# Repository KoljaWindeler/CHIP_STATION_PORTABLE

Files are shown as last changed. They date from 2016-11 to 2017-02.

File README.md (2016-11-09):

# CHIP_STATION_PORTABLE
This project is about a better and gaming compatible housing for C.H.I.P.

PocketChip is a great toy to play with, but the keys tend to be hard to push and make some hard click noises. 
The PSP seems like the perfect housing for a CHIP.

Just to mention some features:
 - it has a parallel display that was almost compatible with chip (only requires small amount of hardware)
 - many buttons (4 for the directions + 4 [x,y,a,b] + 2 shoulder buttons + menu buttons (vol+, vol-, ...) ..)
 - status LEDs for power / charging controllable on the LOW end (+5V is directly connected to the LED) 
 - 3.7V lipo battery which should work directly with chips battery circuit
 - 5V input for charging, perfect for chip
 
The purpose of this project is to create a mainboard that acts as an adapter between C.H.I.P. and the PSP.
It shall have the same form factor as the original PSP mainboard and connect easy to the existing flex connectors,
e.g. the buttons and the display. It shall also carry the DC/DC converter circuit to power the display backlight
and accomplish the conversion of the display signals. It shall also provide the required software and firmware files
for chip to use the PSP hardware.

All this will be documeted at https://bbs.nextthing.co/t/csp-chipstationportable/11171
JKW

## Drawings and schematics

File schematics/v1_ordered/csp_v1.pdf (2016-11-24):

A

A

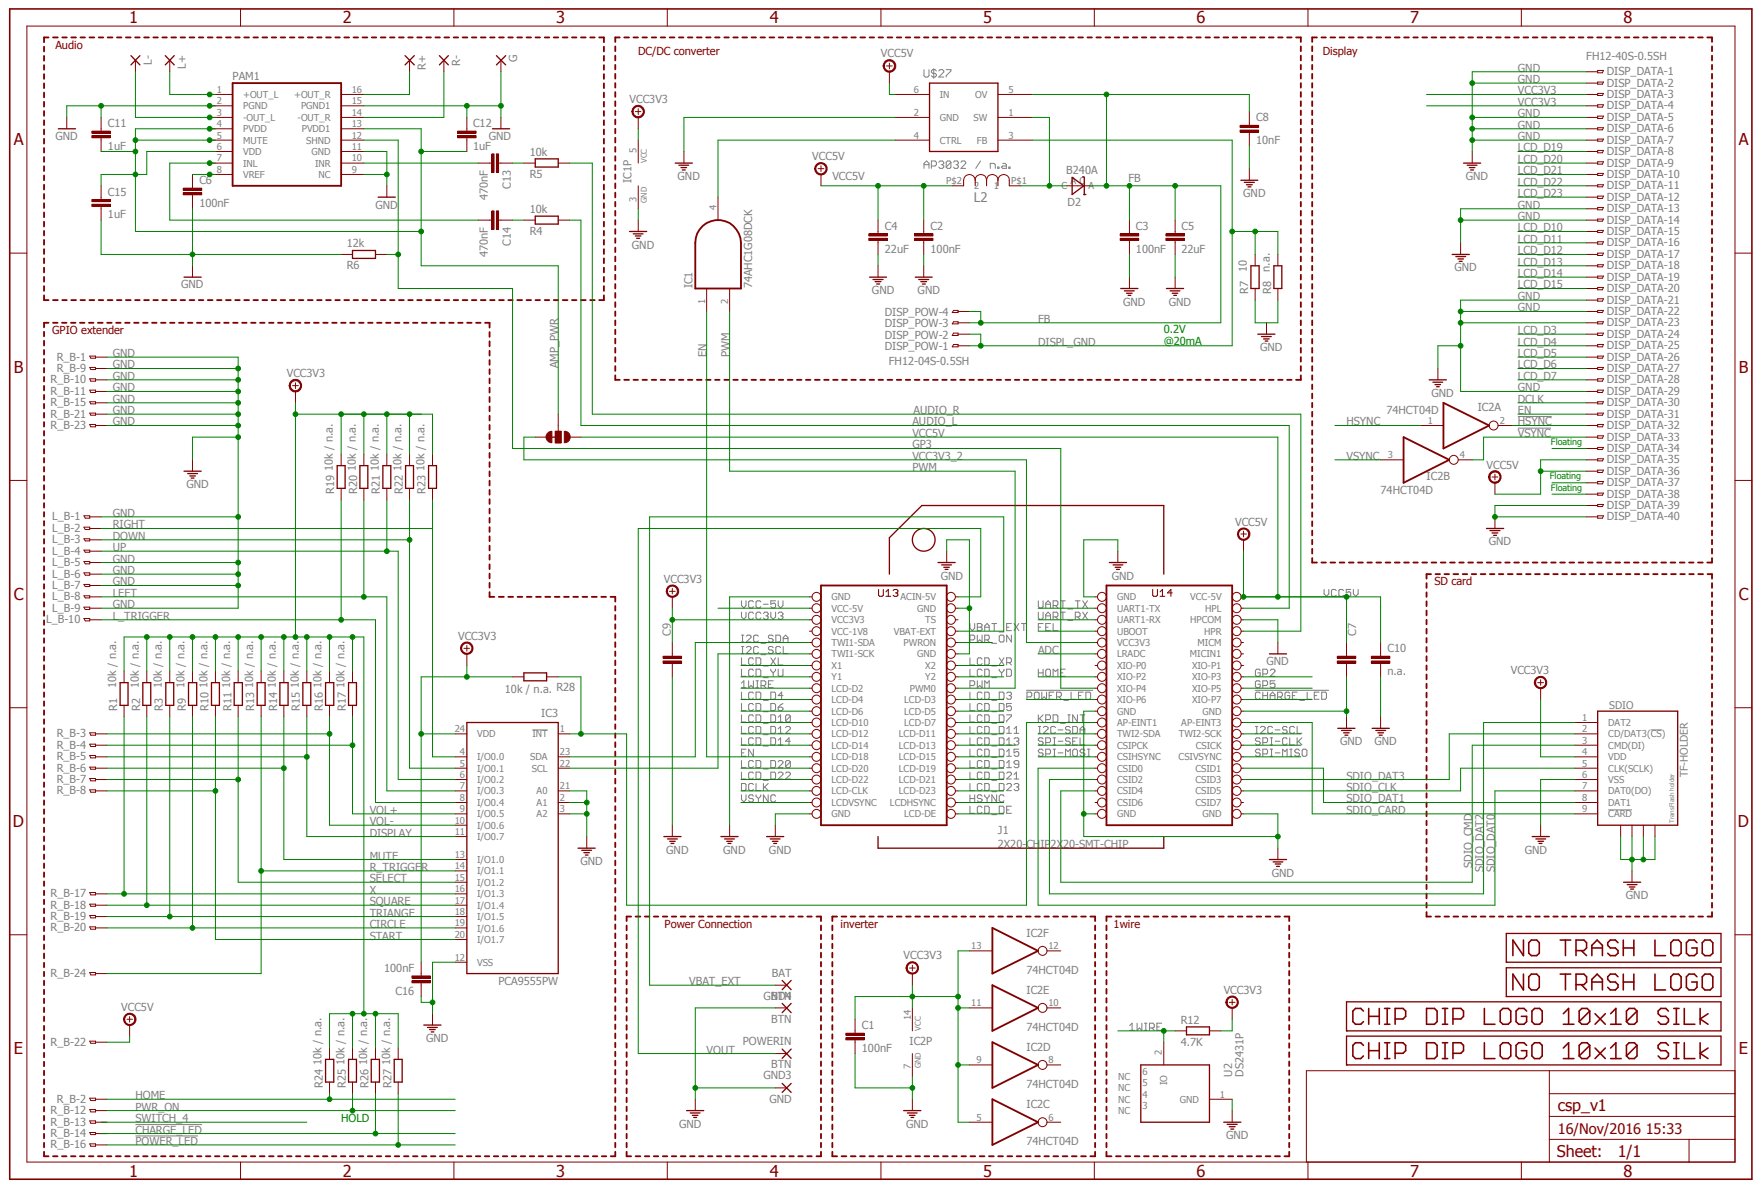
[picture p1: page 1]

VCC3V3_2
PWM

VOL-
DISPLAY
MUTE
SELECT
SQUARE
TRIANGE
CIRCLE
START

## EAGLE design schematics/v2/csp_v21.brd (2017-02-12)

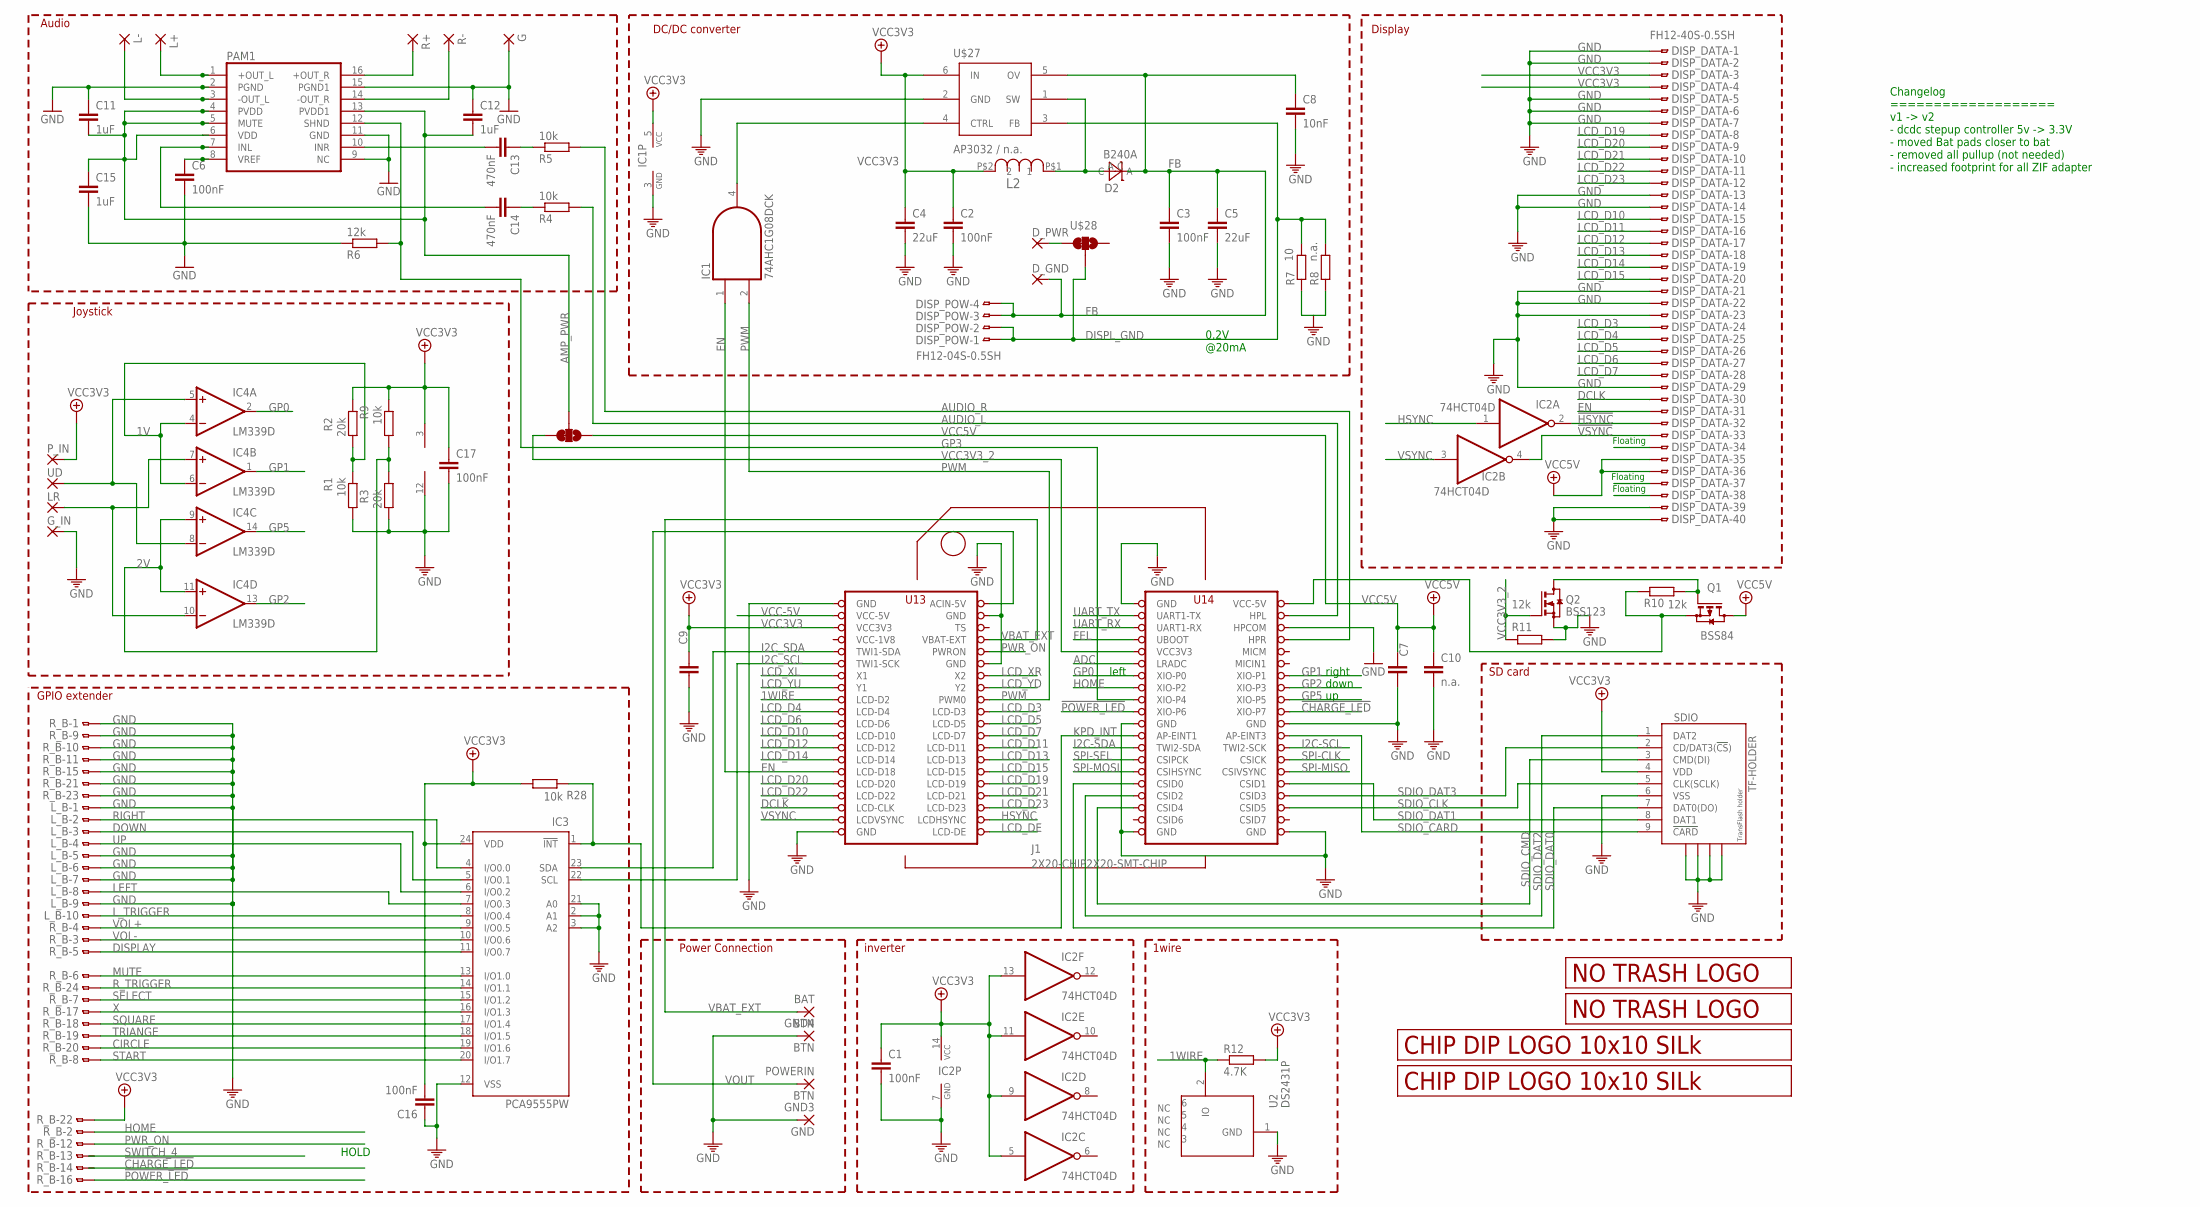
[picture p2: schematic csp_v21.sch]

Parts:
BAT: BTN; SMD1,27-2,54
C1, C2, C3, C6, C16, C17: 100nF; C0805
C4, C5: 22uF; C1206
C7, C9, C10: n.a.; C0805
C8: 10nF; C0805
C11, C12, C15: 1uF; C0805
C13, C14: 470nF; C0805
D2: B240A; DO-214AC
DISP_DATA: FH12-40S-0.5SH
DISP_POW: FH12-04S-0.5SH
D_GND: D_GND; SMD1,36-3
D_PWR: D_PWR; SMD1,36-3
G: 1,6/0,8
GND3: GND; SMD1,27-2,54
GND4: BTN; SMD1,27-2,54
G_IN: BTN; SMD1,36-3
IC1: 74AHC1G08DCK; SC70-5
IC2: 74HCT04D; SO14
IC3: PCA9555PW; TSSOP24
IC4: LM339D; SO14
J1: 2X20-CHIP2X20-SMT-CHIP; 2XAWHW40_G_SMD_R
L2: SRN6045-100M; SRN6045
L+: 1,6/0,8
L-: 1,6/0,8
LR: BTN; SMD1,36-3
L_B: FH12-10S-0.5SH
PAM1: PAM8403; SOP-16
POWERIN: BTN; SMD1,27-2,54
P_IN: BTN; SMD1,36-3
Q1: BSS84; SOT23
Q2: BSS123; SOT23
R1, R9, R28: 10k; M0805
R2, R3: 20k; M0805
R4, R5: 10k; R0805
R6, R10, R11: 12k; R0805
R7: 10; M0805
R8: n.a.; M0805
R12: 4.7K; M0805
R+: 1,6/0,8
R-: 1,6/0,8
R_B: FH12-24S-0.5SH
SDIO: TF-HOLDER; TF-PULL
SJ3: SMD_SJ_3WAY_CLOSED
U2: DS2431P; TSOC6
U$2, U$5: LOGO_10X10_SILK; LOGO2_10X10_SILK
U$3: LOGO_NO_TRASHROHS; LOGO_ROHS_SYM
U$4: LOGO_NO_TRASHNO_TRASH; LOGO_ROHS_NO_TRASH
U$27: AP3032 / n.a.; SOT23-6
U$28: SMD_SJ_3WAY_CLOSED
UD: BTN; SMD1,36-3

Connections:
1V: IC4.4 (-IN), IC4.6 (-IN), R1.1, R2.2
1WIRE: J1.LCD-D2, R12.1, U2.2 (IO)
2V: IC4.9 (+IN), IC4.11 (+IN), R3.1, R9.2
!CHARGE_LED: J1.XIO-P7, R_B.14
!HSYNC: DISP_DATA.32, IC2.2 (O)
!POWER_LED: J1.XIO-P6, R_B.16
!VSYNC: DISP_DATA.33, IC2.4 (O)
ADC: J1.LRADC
AMP_PWR: C11.2, C12.2, C15.1, PAM1.4 (PVDD), PAM1.5 (MUTE), PAM1.6 (VDD), PAM1.13 (PVDD1), SJ3.2
AUDIO_L: J1.HPL, R4.2
AUDIO_R: J1.HPR, R5.2
CIRCLE: IC3.19 (I/O1.6), R_B.20
DCLK: DISP_DATA.30, J1.LCD-CLK
DISPLAY: IC3.11 (I/O0.7), R_B.5
DISPL_GND: DISP_POW.1, DISP_POW.2, R7.2, R8.2, U$27.3 (FB), U$28.2
DOWN: IC3.5 (I/O0.1), L_B.3
EN: DISP_DATA.31, IC1.1 (I0), J1.LCD-D18
FB: C3.1, C5.1, C8.1, D2.C, DISP_POW.3, DISP_POW.4, D_GND.P$1, U$27.5 (OV)
FEL: J1.FEL (UBOOT)
GND: C1.2, C2.2, C3.2, C4.2, C5.2, C6.2, C7.2, C8.2, C9.2, C10.2, C11.1, C12.1, C15.2, C16.1, C17.2, DISP_DATA.1, DISP_DATA.2, DISP_DATA.5, DISP_DATA.6, DISP_DATA.7, DISP_DATA.13, DISP_DATA.14, DISP_DATA.21, DISP_DATA.22, DISP_DATA.23, DISP_DATA.29, DISP_DATA.39, DISP_DATA.40, G.1, GND3.1, GND4.1, G_IN.P$1, IC1.3 (GND), IC2.7 (GND), IC3.2 (A1), IC3.3 (A2), IC3.12 (VSS), IC3.21 (A0), IC4.12 (GND), J1.GND@1 (GND), J1.GND@2 (GND), J1.GND@3 (GND), J1.GND@4 (GND), J1.GND@5 (GND), J1.GND@6 (GND), J1.GND@7 (GND), J1.GND@8 (GND), J1.GND@10 (GND), J1.HPCOM, L_B.1, L_B.5, L_B.6, L_B.7, L_B.9, PAM1.2 (PGND), PAM1.9 (NC), PAM1.11 (GND), PAM1.15 (PGND1), Q2.2 (S), R1.2, R3.2, R6.1, R7.1, R8.1, R11.1, R_B.1, R_B.9, R_B.10, R_B.11, R_B.15, R_B.21, R_B.23, SDIO.6 (VSS), SDIO.S1, SDIO.S2, SDIO.S3, SDIO.S4, U2.1 (GND), U$27.2 (GND)
GP0: IC4.2 (OUT), J1.XIO-P0
GP1: IC4.1 (OUT), J1.XIO-P1
GP2: IC4.13 (OUT), J1.XIO-P3
GP3: J1.XIO-P4, PAM1.12 (SHND), R6.2
GP5: IC4.14 (OUT), J1.XIO-P5
HOME: J1.XIO-P2, R_B.2
HSYNC: IC2.1 (I), J1.LCD-HSYNC (LCDHSYNC)
I2C-SCL: J1.TWI2-SCK
I2C-SDA: J1.TWI2-SDA
I2C_SCL: IC3.22 (SCL), J1.TWI1-SCK
I2C_SDA: IC3.23 (SDA), J1.TWI1-SDA
INL: C14.2, PAM1.7 (INL)
INR: C13.2, PAM1.10 (INR)
KPD_INT: IC3.1 (!INT), J1.AP-EINT1, R28.1
L+OUT: L+.1, PAM1.1 (+OUT_L)
L-OUT: L-.1, PAM1.3 (-OUT_L)
LCD_D3: DISP_DATA.24, J1.LCD-D3
LCD_D4: DISP_DATA.25, J1.LCD-D4
LCD_D5: DISP_DATA.26, J1.LCD-D5
LCD_D6: DISP_DATA.27, J1.LCD-D6
LCD_D7: DISP_DATA.28, J1.LCD-D7
LCD_D10: DISP_DATA.15, J1.LCD-D10
LCD_D11: DISP_DATA.16, J1.LCD-D11
LCD_D12: DISP_DATA.17, J1.LCD-D12
LCD_D13: DISP_DATA.18, J1.LCD-D13
LCD_D14: DISP_DATA.19, J1.LCD-D14
LCD_D15: DISP_DATA.20, J1.LCD-D15
LCD_D19: DISP_DATA.8, J1.LCD-D19
LCD_D20: DISP_DATA.9, J1.LCD-D20
LCD_D21: DISP_DATA.10, J1.LCD-D21
LCD_D22: DISP_DATA.11, J1.LCD-D22
LCD_D23: DISP_DATA.12, J1.LCD-D23
LCD_DE: J1.LCD-DE
LCD_XL: J1.X1
LCD_XR: J1.X2
LCD_YD: J1.Y2
LCD_YU: J1.Y1
LEFT: IC3.7 (I/O0.3), L_B.8
L_TRIGGER: IC3.8 (I/O0.4), L_B.10
MUTE: IC3.13 (I/O1.0), R_B.6
unnamed: IC1.4 (O), U$27.4 (CTRL)
unnamed: J1.VCC-5V@2 (VCC-5V), Q1.2 (S), R10.2
unnamed: D_PWR.P$1, U$28.1
unnamed: IC4.5 (+IN), IC4.8 (-IN), UD.P$1
unnamed: IC4.7 (+IN), IC4.10 (-IN), LR.P$1
unnamed: Q1.1 (G), Q2.3 (D), R10.1
unnamed: C6.1, PAM1.8 (VREF)
unnamed: C14.1, R4.1
unnamed: C13.1, R5.1
PWM: IC1.2 (I1), J1.PWM0
PWR_ON: J1.PWRON, R_B.12
R+OUT: PAM1.16 (+OUT_R), R+.1
R-OUT: PAM1.14 (-OUT_R), R-.1
RIGHT: IC3.4 (I/O0.0), L_B.2
R_TRIGGER: IC3.14 (I/O1.1), R_B.24
SDIO_CARD: J1.AP-EINT3, SDIO.9 (!CARD)
SDIO_CLK: J1.CSID5, SDIO.5 (CLK(SCLK))
SDIO_CMD: J1.CISD4 (CSID4), SDIO.3 (CMD(DI))
SDIO_DAT0: J1.CSID0, SDIO.7 (DAT0(DO))
SDIO_DAT1: J1.CSID1, SDIO.8 (DAT1)
SDIO_DAT2: J1.CSID2, SDIO.1 (DAT2)
SDIO_DAT3: J1.CSID3, SDIO.2 (CD/DAT3(!CS!))
SELECT: IC3.15 (I/O1.2), R_B.7
SPI-CLK: J1.CSICK
SPI-MISO: J1.CSIVSYNC
SPI-MOSI: J1.CSIHYSYNC (CSIHSYNC)
SPI-SEL: J1.CSPICK (CSIPCK)
SQUARE: IC3.17 (I/O1.4), R_B.18
START: IC3.20 (I/O1.7), R_B.8
SWITCH_4: R_B.13
TRIANGE: IC3.18 (I/O1.5), R_B.19
UART_RX: J1.UART1-RX
UART_TX: J1.UART1-TX
UP: IC3.6 (I/O0.2), L_B.4
VBAT_EXT: BAT.1, J1.BAT (VBAT-EXT)
VCC3V3: C1.1, C2.1, C4.1, C9.1, C16.2, C17.1, DISP_DATA.3, DISP_DATA.4, IC1.5 (VCC), IC2.5 (I), IC2.9 (I), IC2.11 (I), IC2.13 (I), IC2.14 (VCC), IC3.24 (VDD), IC4.3 (V+), J1.VCC3V3@2 (VCC3V3), L2.P$2 (2), P_IN.P$1, R2.1, R9.1, R12.2, R28.2, R_B.22, SDIO.4 (VDD), U$27.6 (IN)
VCC3V3_2: J1.VCC3V3@1 (VCC3V3), Q2.1 (G), R11.2, SJ3.1
VCC5V: C7.1, C10.1, DISP_DATA.35, DISP_DATA.36, Q1.3 (D), SJ3.3
VCC-1V8: J1.VCC1V8 (VCC-1V8)
VCC-5V: J1.VCC-5V@1 (VCC-5V)
VOL+: IC3.9 (I/O0.5), R_B.4
VOL-: IC3.10 (I/O0.6), R_B.3
VOUT: J1.CHG-IN (ACIN-5V), POWERIN.1
VREG_OUTPUT: D2.A, L2.P$1 (1), U$27.1 (SW)
VSYNC: IC2.3 (I), J1.LCD-VSYNC (LCDVSYNC)
X: IC3.16 (I/O1.3), R_B.17

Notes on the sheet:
Power Connection
Audio
DC/DC converter
0.2V @20mA
Floating
HOLD
GPIO extender
SD card
Display
inverter
1wire
Changelog =================== v1 -> v2 - dcdc stepup controller 5v -> 3.3V - moved Bat pads closer to bat - removed all pullup (not needed) - increased footprint for all ZIF adapter
Joystick
left
right
down

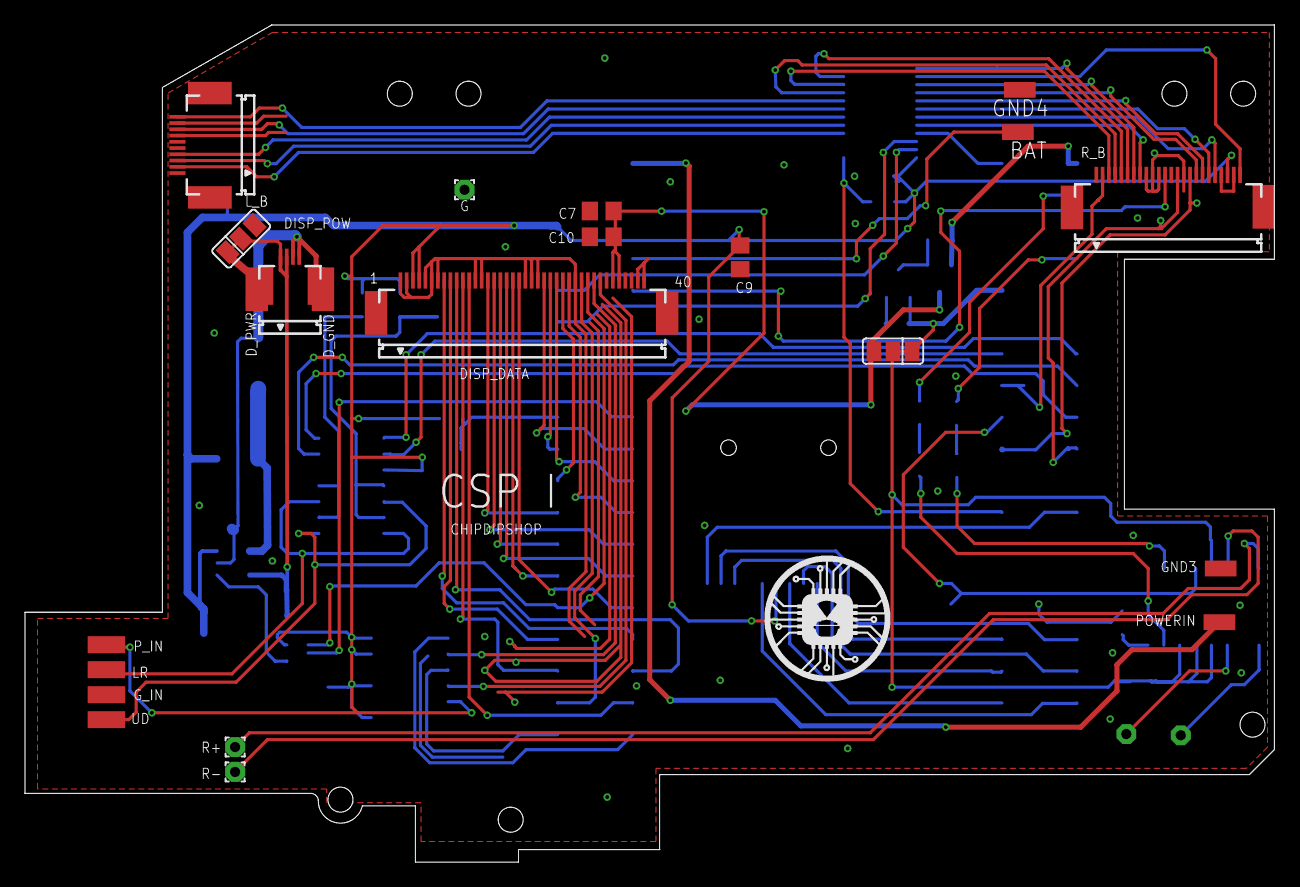
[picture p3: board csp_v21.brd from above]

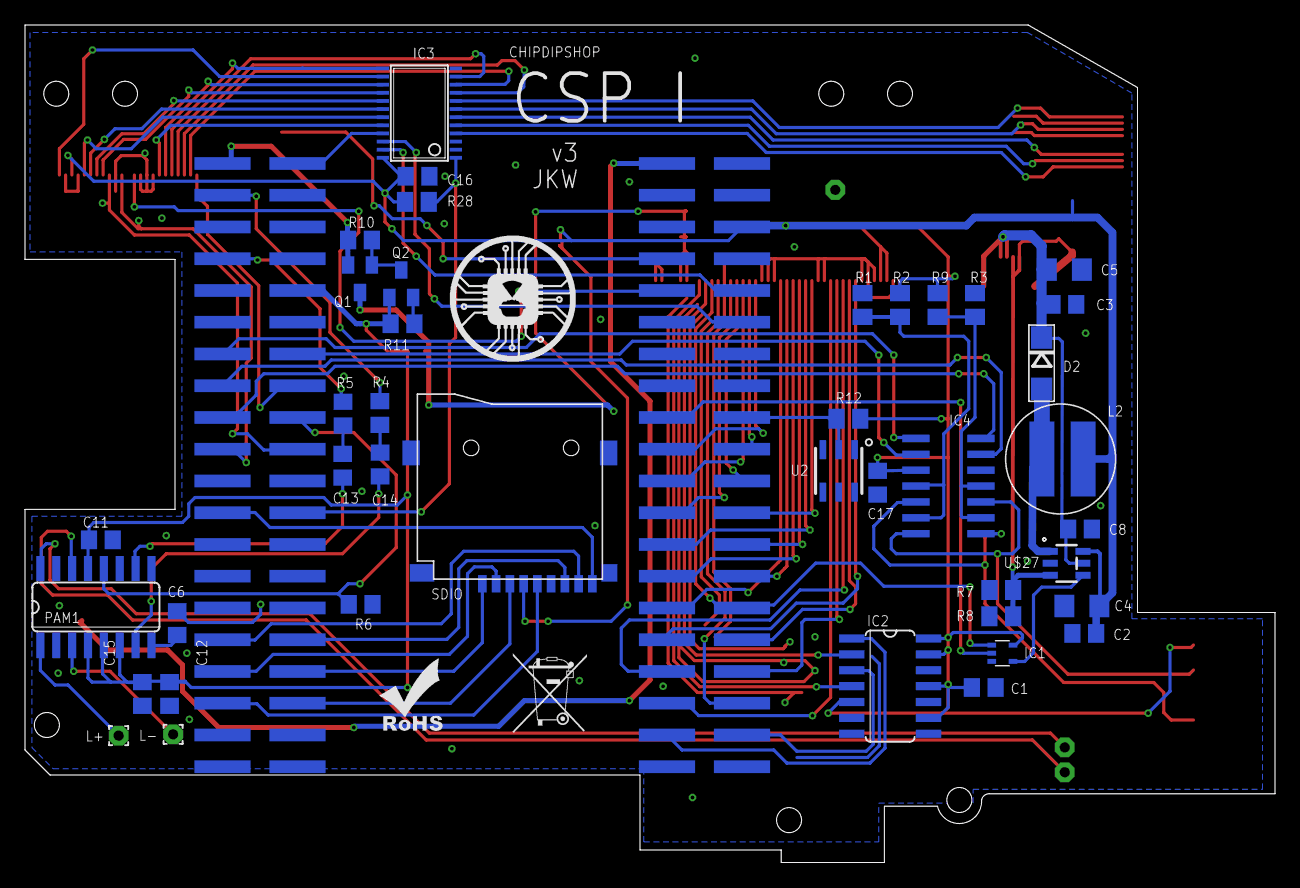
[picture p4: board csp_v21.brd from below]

Board: 2 copper layers, 100.0 x 67.0 mm, 68 parts (44 on the bottom side), 88 nets.

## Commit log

2016-11-06 init commit
    [csp_v1.GBL, csp_v1.GBO, csp_v1.GBP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]
2016-11-07 changed display driver to adopt to changes
2016-11-08 optimized schematic to one page
    [csp_v1.brd, csp_v1.sch]
2016-11-16 flip p5 to p6 in schematic, to account for bug, no layout change
    [csp_v1.brd, csp_v1.sch]
2016-11-30 added v2 draft
    [csp_v2.brd, csp_v2.sch]
2016-11-30 updated layout
    [csp_v2.brd, csp_v2.sch]
2016-12-04 improved v2
    [csp_v1.GBL, csp_v1.GBO, csp_v1.GBP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]
2016-12-04 added gitignore
    [csp_v2.sch]
2016-12-08 replaced quote
    [quotation.xlsx, quotation_assumtions.xlsx]
2016-12-08 added v2.1, with 5V switchable to avoid discharge
    [csp_v2.csv, csp_v21.brd, csp_v21.sch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]
2017-01-16 Fixed Op-amp, position of thumb still wrong
    [csp_v2.brd, csp_v2.sch, csp_v21.brd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]
2017-02-12 moved pads for analog input
    [csp_v21.brd, csp_v21.sch, quotation.xlsx]

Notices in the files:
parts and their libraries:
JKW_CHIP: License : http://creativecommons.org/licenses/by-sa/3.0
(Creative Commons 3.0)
